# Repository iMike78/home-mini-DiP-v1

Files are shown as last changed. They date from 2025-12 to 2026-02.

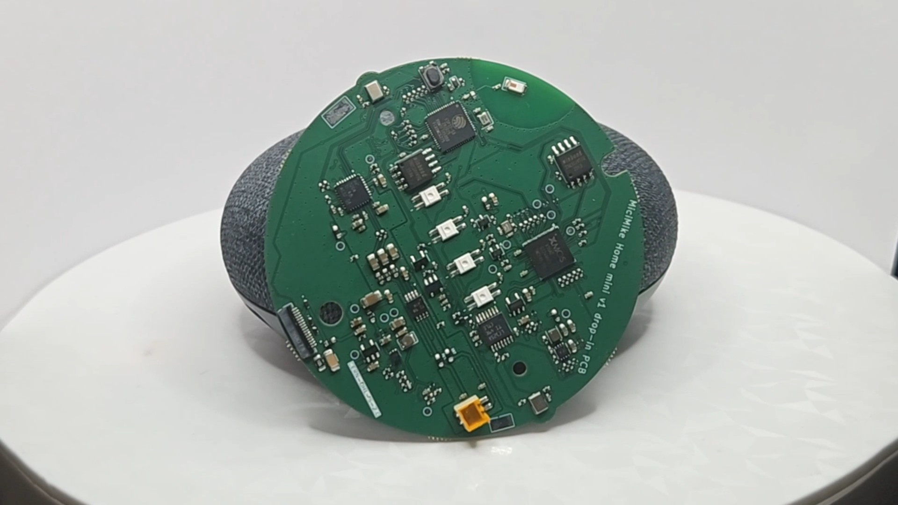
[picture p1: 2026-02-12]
pics/dji_export_photo_20260208104227295.png

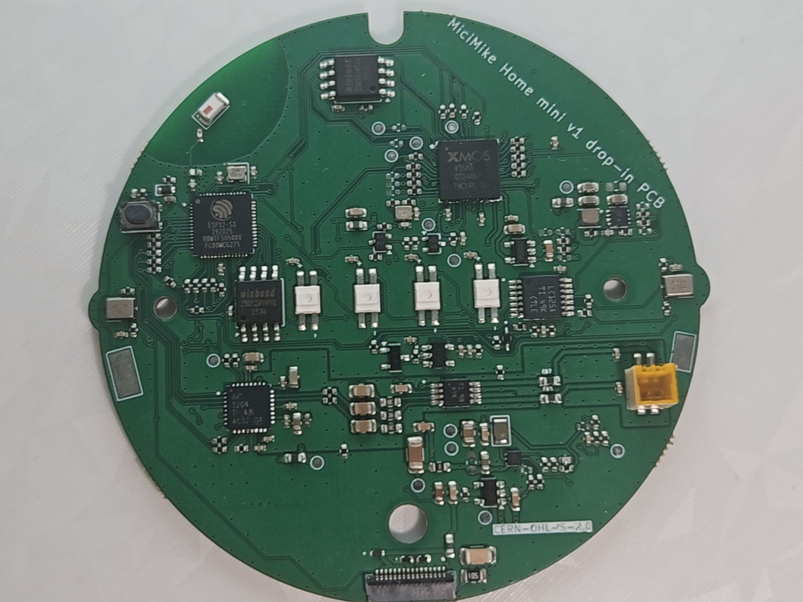
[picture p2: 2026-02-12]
pics/DJI_20260208_104004_14.jpg

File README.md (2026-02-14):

# MiciMike drop-in PCB replacement for Google Home Mini (Gen-1)

[MiciMike Home Mini](https://github.com/iMike78/home-mini-v1-drop-in-pcb) is a drop-in PCB replacement for the ["Google Home Mini" (Google's first-generation smart speaker hardware with a Micro-USB charging port)](https://en.wikipedia.org/wiki/Google_Nest_(smart_speakers)), but based on ESP32 and XMOS microcontrollers for running open-source firmware.

dji_export_photo_20260208104256661

Tip! If you are instead looking for a similar drop-in PCB replacement for the "Google Nest Mini" (Google's second-generation smart speaker with a barrel connector charging port) then check out the sister-project at https://github.com/iMike78/nest-mini-drop-in-pcb

Both of these are fully open-source hardware projects, taking some concep inspiration from the [Onju Voice](https://github.com/justLV/onju-voice) however aiming to follow [Open Home Foundation's open voice assistants standard with Home Assistant Voice Preview Edition as reference](https://www.home-assistant.io/blog/2024/12/19/voice-preview-edition-the-era-of-open-voice/) for PCB designs and specifications.

# Project scope

The goal of this project/repository and its sister-project (which are both similar to the concept in [Onju Voice](https://github.com/justLV/onju-voice) but under a fully open-source hardware license) is to design drop-in replacement PCBs (Printed Circuit Board) with hardware schematics following open voice assistants standard from the Open Home Foundation so that anyone can make or order from a one-stop PCB manufacturer as a custom drop-in replacement PCB for the Google Nest Mini (2nd Gen) to convert it into open-source voice assistant hardware.

These projects is primarly targeting people looking to repurpose their old Google Home Mini (and Google Nest Mini) smart speakers into open-source hardware for [Voice Control of Home Assistant](https://www.home-assistant.io/voice_control/) and/or media player speaker output for [Music Assistant](https://www.music-assistant.io), (the hardware can however probably also be used with other applications as well with other firmware as it is based on the popular Espressif ESP32 platform).

The hardware design will (similar to [Home Assistant Voice Preview Edition](https://www.home-assistant.io/blog/2024/12/19/voice-preview-edition-the-era-of-open-voice/)) integrate an ESP32-S3 microcontroller for WiFi, BLE, and [onboard wake-word detection](https://www.home-assistant.io/voice_control/about_wake_word/) (using the no-code [ESPHome firmware](https://esphome.io/) firmware) + an XMOS xCORE XU316 chip for advanced audio processing (with custom firmware for microphone cleanup offloading for better voice recognition capabilities by using using locally running algorithms for Noise Suppression, Acoustic Echo Cancellation, Interference Cancellation, and Automatic Gain Control).

Again, functionality-wise it is made to be mostly hardware comatible with the [Home Assistant Voice Preview Edition (a.k.a. Home Assistant Voice PE](https://www.home-assistant.io/blog/2024/12/19/voice-preview-edition-the-era-of-open-voice/) reference design (which has been released as open-source hardware design from Open Home Foundation in coolaboration with Nabu Casa). The main difference will be due to very tight constraints defined by the Google Home Mini and Google Nest Mini enclosures and its other comonents, (the design of the replacement PCBs will therefore be limited by the same type of physical capacity inputs as the original hardware from Google).

As such the scope for these projects is not to develop new features/functions for the ESPHome and XMOS firmware, so if you want that then you instead need to turn to the firmware development of the Home Assistant Voice Preview Edition as well as to the upstream ESPHome repositories on GitHub:

- https://github.com/esphome/home-assistant-voice-pe
  - https://github.com/esphome/esphome
    - https://github.com/esphome/voice-kit-xmos-firmware

## Request for collaboration and contributions

If you are a non-developer and would like to show your support me working on these projects please consider [buying me a coffee via Ko-fi](https://ko-fi.com/imike78) ☕ 

If you have experience with board-level electrical design / working with PCB design andlayout in CAD software (epecially with PCB routing and ground pouring in KiCad, or optimizing noise-sensitive digital+analog layouts), then **your help would be highly appreciated**! Please feel free to open a new issue and add comments to existing issues, or start a new discussion in this repository to suggestions/requests/input/feedback.

For reference, you can find some more background information about the original concept/idea see and post to Home Assistant related community discussion in this Home Assistant community forum thread:

- https://community.home-assistant.io/t/any-news-on-alternative-to-onju-voice-pcb-repacement-design-for-google-nest-home-mini-speakers-with-added-xmos-chip-to-match-of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

### Current status

- ✅ Schematic completed
- ✅ Component placement done
- ✅ Routing
- ✅ Ground pour, shielding strategy, and EMI considerations
- ✅ Test run of the first test batch
- ✅ Ready for manufacturing

## Tools used

- 🛠️ KiCad 9
- 🧰 SnapEDA / LCSC for footprint sourcing

## Known hardware specifications

- 4-layer PCB
- ESP32-S3R8 bare chip (ESP32-S3 for WiFi, BLE, and onboard wake-word detection) with 16MB flash
- XMOS XU316-1024-QF60B-C24 (XMOS XU316 xCORE DSP audio processing) with 4MB flash
- Dual I²S buses (to allow I2S interfaces at the same time, i.e. simultaneous audio output and audio input)
- AIC3204 DAC and TPA6211 PA for speaker output
- 2x MEMS microphones (dual T3902 with 68mm inter-mic spacing)
- 4x SK6812 RGB LEDs

## References

### Home Assistant Voice Preview Edition resources including PCB design files
- https://www.home-assistant.io/blog/2024/12/19/voice-preview-edition-the-era-of-open-voice/
  - https://voice-pe.home-assistant.io/resources/
    - https://support.nabucasa.com/hc/en-us/categories/24451727188125-Home-Assistant-Voice-Preview-Edition
      - https://support.nabucasa.com/hc/en-us/sections/24980381645213-Resources

#### ESPHome firmware for Home Assistant Voice PE (which also use the same ESP32-S3 + XMOS XU316 combination):

- https://github.com/esphome/home-assistant-voice-pe
  - https://esphome.github.io/home-assistant-voice-pe/
- https://voice-pe.home-assistant.io/

### XMOS xCORE DSP (XU316-1024-QF60B-C32) MCU IC chip

- https://www.xmos.com/download/XU316-1024-QF60B-xcore.ai-Datasheet(3).pdf
- https://www.xmos.com/software-tools/
  - https://www.xmos.com/develop/xcore-voice
  - https://www.xmos.com/usb-multichannel-audio/
  - https://www.xmos.com/xcore-ai
 
#### XMOS firmware from the ESPHome prokect for the Home Assistant Voice Preview Edition hardware:

- https://github.com/esphome/voice-kit-xmos-firmware
  - https://github.com/esphome/xmos_fwk_rtos
  - https://github.com/esphome/xmos_fwk_io

## License

This project is licensed under the [CERN Open Hardware License Version 2 - Strongly Reciprocal (CERN-OHL-S v2)]
Any modified version of this hardware must also be distributed under the same license.

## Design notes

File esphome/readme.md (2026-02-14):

# MiciMike Factory Firmware Structure

## Overview

The factory firmware structure enables:
1. Minimal factory firmware pre-installed at manufacturing
2. Initial setup via BLE Improv for WiFi configuration
3. Automatic upgrade to full firmware after WiFi connection

## File Structure

```
esphome/
├── micimike-factory.yml          # Factory firmware (manufacturing)
└── micimike-voice.yml            # Full firmware (your current config)
```

## Factory Firmware (micimike-factory.yml)

### Main Components:

1. **Package Import**: Loads the full firmware configuration
   ```yaml
   packages:
     micimike_voice: !include micimike-voice.yml
   ```

2. **BLE Improv Provisioning**: 
   - Uses touch center button for authentication
   - BLE connection for WiFi setup
   
3. **HTTP OTA Update**:
   - Downloads manifest from GitHub releases
   - Automatically updates to full firmware

4. **Beta Firmware Switch**:
   - Enables beta version testing
   - Switches manifest URL between production/beta

## Key Differences from HA VPE:

### 1. Center Button Authorizer
HA VPE: `authorizer: center_button` (physical button)
MiciMike: `authorizer: center_button` (touch button - ESP32-S3 GPIO3)

The touch button works the same as physical:
```yaml
binary_sensor:
  - platform: esp32_touch
    id: center_button
    threshold: 5000
    pin: GPIO3
```

### 2. LED Control
The factory firmware also supports the `control_leds` script:
- During BLE provisioning: `improv_ble_in_progress = true`
- During initialization: `init_in_progress = true`
- After WiFi connection: normal LED operation

## Installation Process

### 1. Flash Factory Firmware (USB)
```bash
esphome run micimike-factory.yml
```

### 2. BLE Improv Provisioning
- Device starts in AP mode
- ESPHome app or Home Assistant discovers it
- Touch center button for authentication
- WiFi configuration

### 3. Automatic Update
- 5 second delay after WiFi connection
- BLE disable
- HTTP OTA downloads manifest
- Automatic update to full firmware
- Reboot with full functionality

## Manifest.json Structure

GitHub releases must contain a manifest.json:

```json
{
  "name": "MiciMike Voice Assistant",
  "version": "v0.9.0",
  "builds": [
    {
      "chipFamily": "ESP32-S3",
      "improv": false,
      "parts": [
        {
          "path": "micimike-voice.bin",
          "offset": 0
        }
      ]
    }
  ]
}
```

## GitHub Releases Structure

```
Releases/
├── v0.9.0/
│   ├── manifest.json           # Production manifest
│   ├── manifest-beta.json      # Beta manifest
│   └── micimike-voice.bin      # Full firmware binary
```

## Benefits

1. **Simple Manufacturing**: Only factory firmware needs to be flashed
2. **OTA Updates**: Users receive full version via WiFi
3. **Beta Channel**: Optional beta firmware testing
4. **No USB Dependency**: After initial flash, everything is OTA
5. **Version Tracking**: GitHub releases-based version management

## Notes

- Touch center button works as authentication just like physical button
- All full configuration functionality is preserved
- Factory firmware contains only bootstrap functions
- LED control works in both versions
- Future Firmware updates are not automatic. Users must manually check for new releases and update via ESPHome Dashboard.

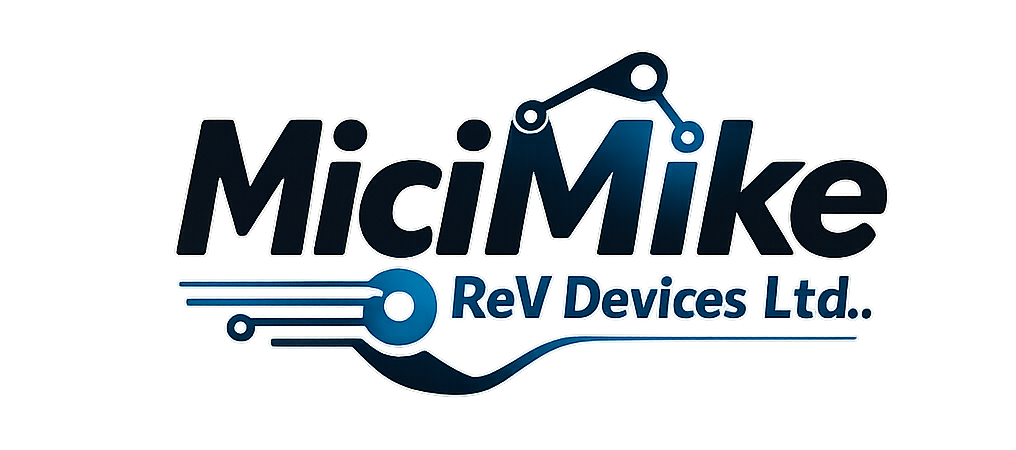
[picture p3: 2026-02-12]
pics/MiciMike.png

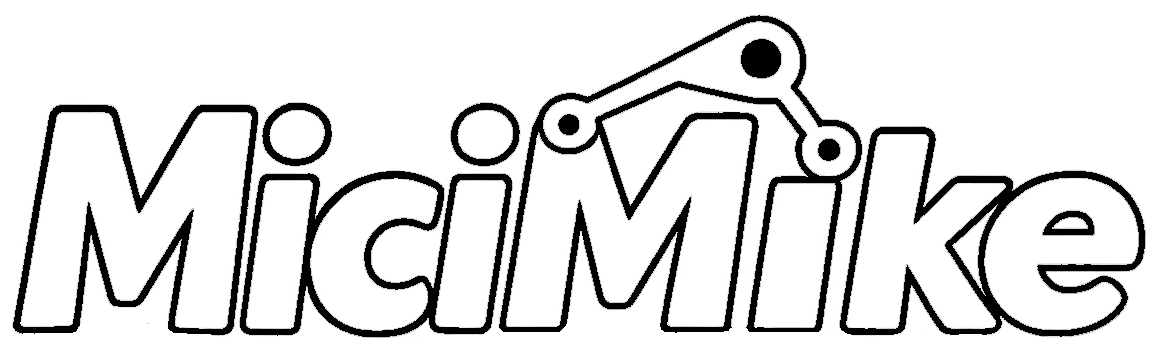
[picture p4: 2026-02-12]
pics/MiciMike_silkscreen.png

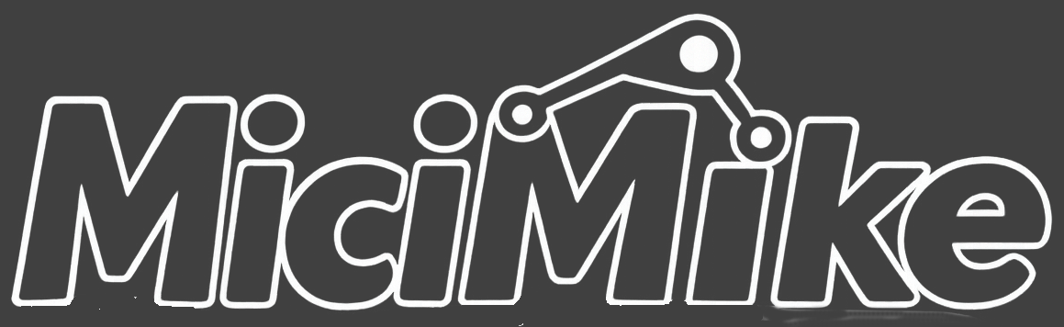
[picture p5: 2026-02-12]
[Originals]/MiciMike_silkscreen.png

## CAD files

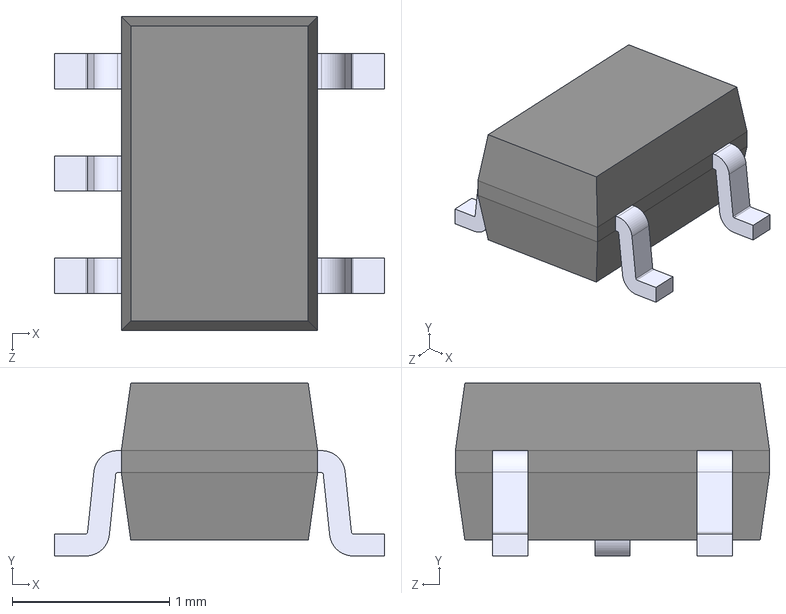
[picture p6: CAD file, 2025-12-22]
parts/MIC5365-1.8YC5-TR.step
2.10 x 1.10 x 2.00 mm

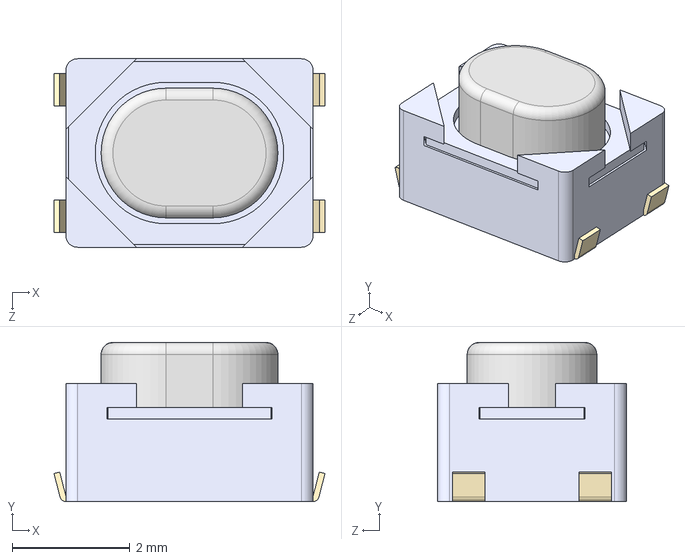
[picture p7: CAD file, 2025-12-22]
parts/PTS810SJS250SMTRLFS--3DModel-STEP-56544.STEP
4.60 x 2.70 x 3.20 mm

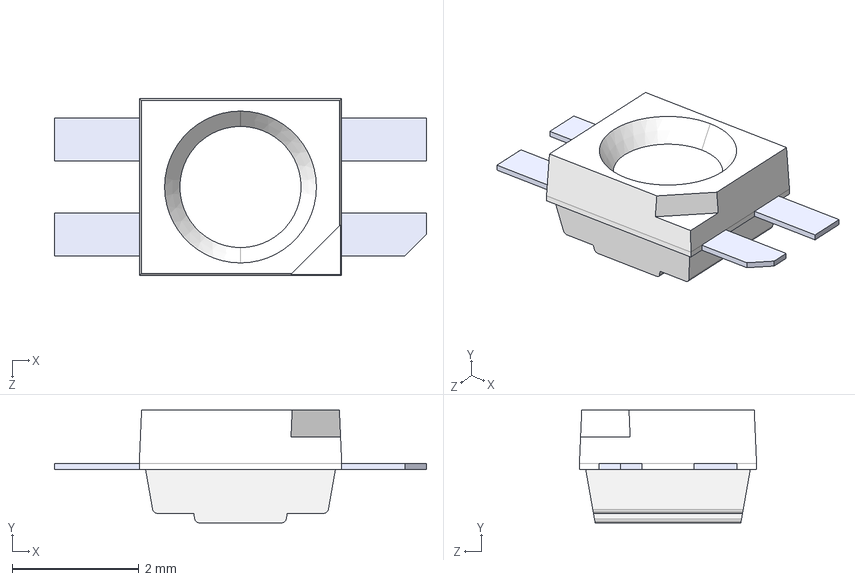
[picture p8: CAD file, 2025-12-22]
parts/SK6812-E.step
5.88 x 1.78 x 2.80 mm

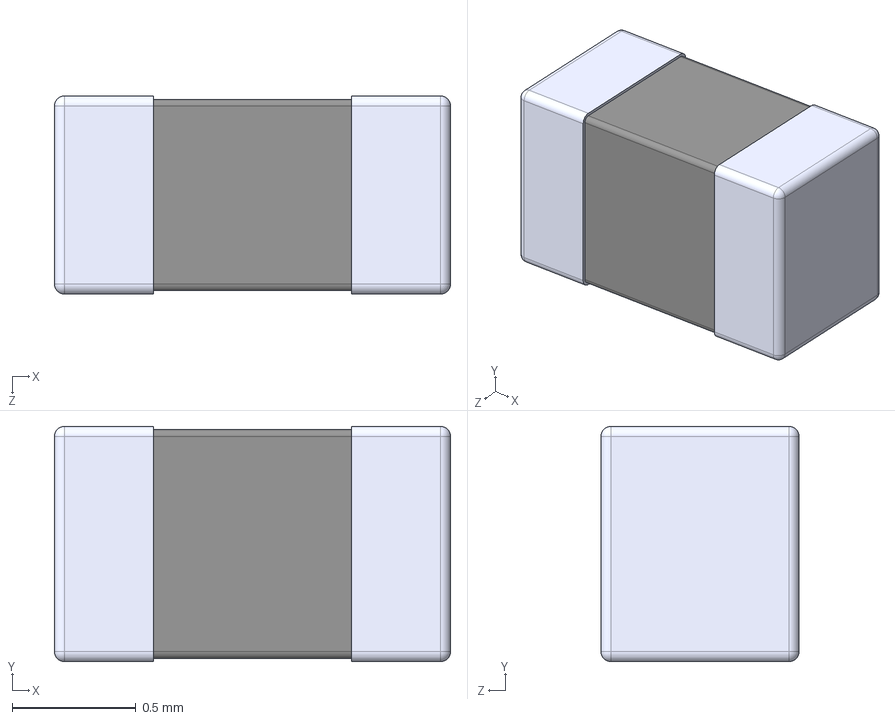
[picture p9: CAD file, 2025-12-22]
parts/BLM18PG121SN1D.step
1.60 x 0.95 x 0.8 mm

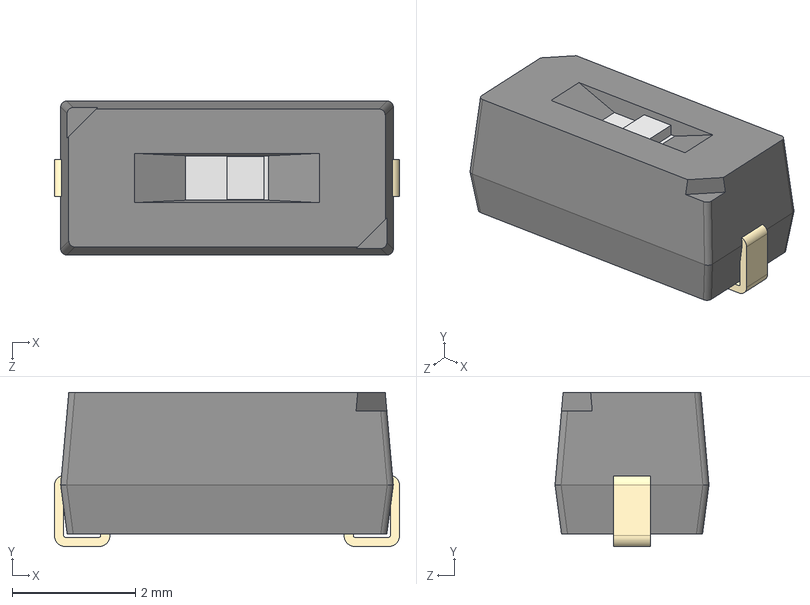
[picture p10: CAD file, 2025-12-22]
parts/CHS-01TA.step
5.60 x 2.50 x 2.50 mm
CHS-01 body
pin^CHS-01xx
switch^CHS-01xx

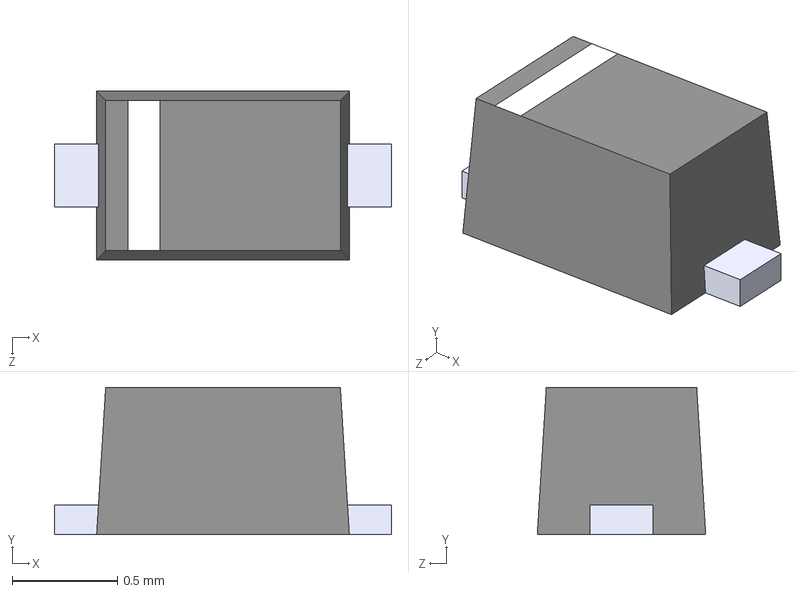
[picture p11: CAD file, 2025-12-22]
parts/RB521S30T1G.step
1.60 x 0.7 x 0.8 mm

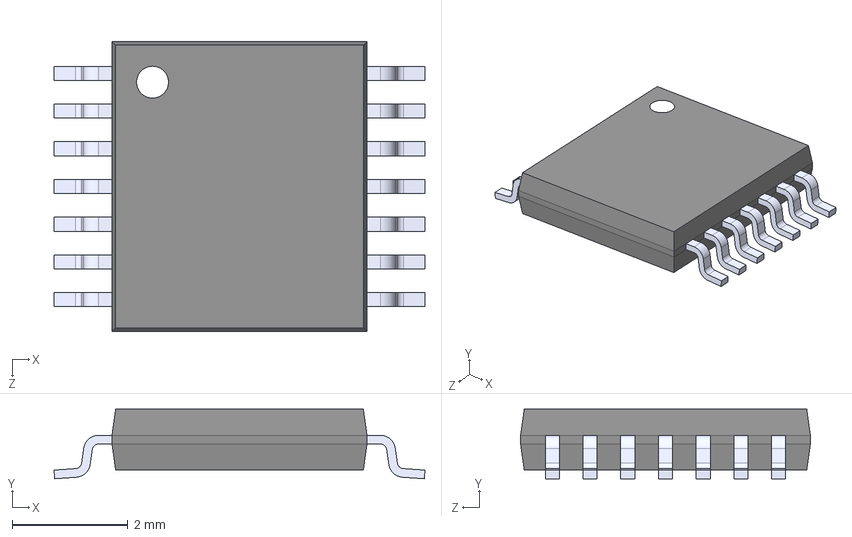
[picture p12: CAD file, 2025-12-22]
parts/SN74LVC125APWR.step
6.40 x 1.20 x 5.00 mm

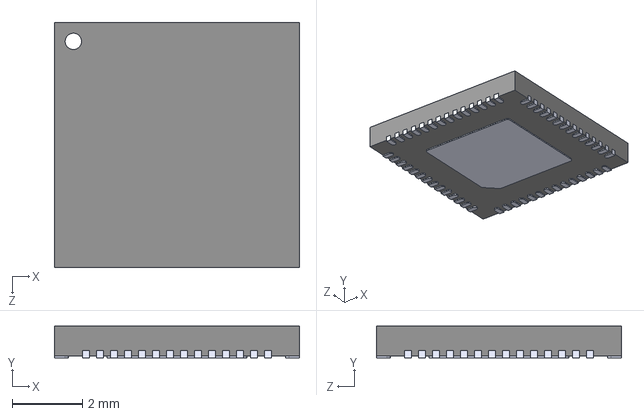
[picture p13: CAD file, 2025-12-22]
parts/ESP32-S3R8.step
7.00 x 0.9 x 7.00 mm

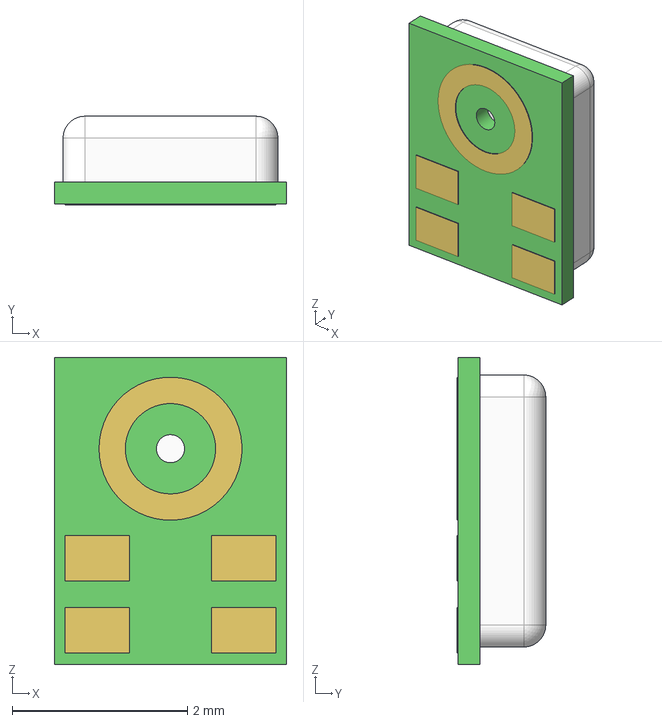
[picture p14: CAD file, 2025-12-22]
parts/DMM-3526-B-R.step
2.65 x 1.01 x 3.50 mm

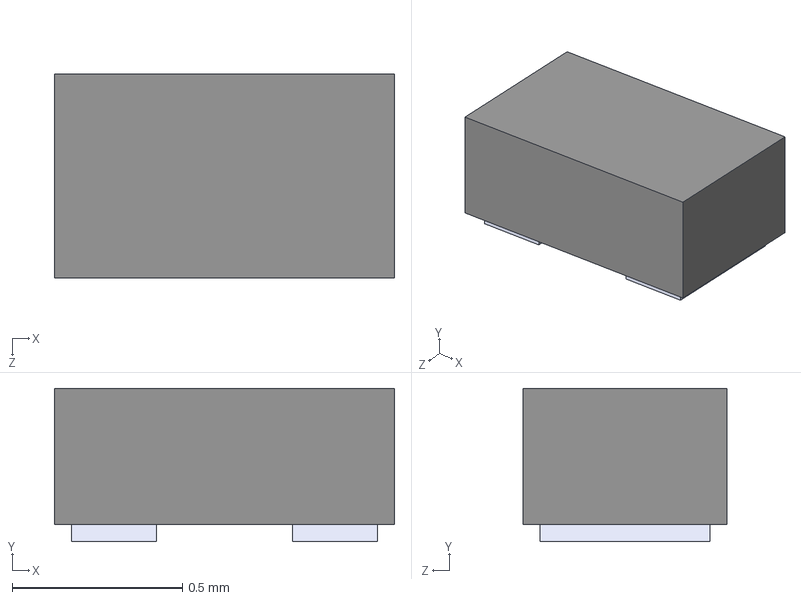
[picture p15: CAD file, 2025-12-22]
parts/TPD1E10B06DPYR.step
1.00 x 0.45 x 0.6 mm

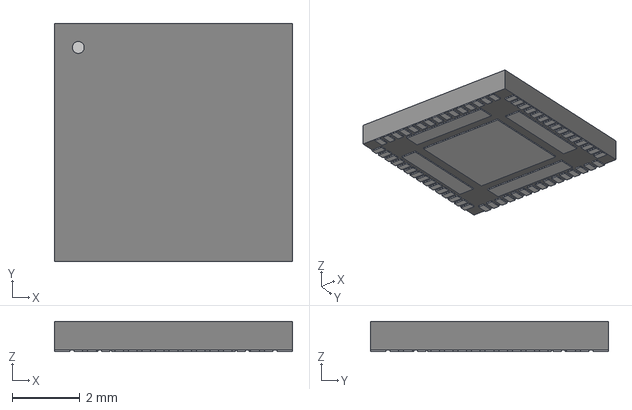
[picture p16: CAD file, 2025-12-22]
parts/QFN_F60B-C24_XMO.step
7.01 x 7.01 x 0.892 mm

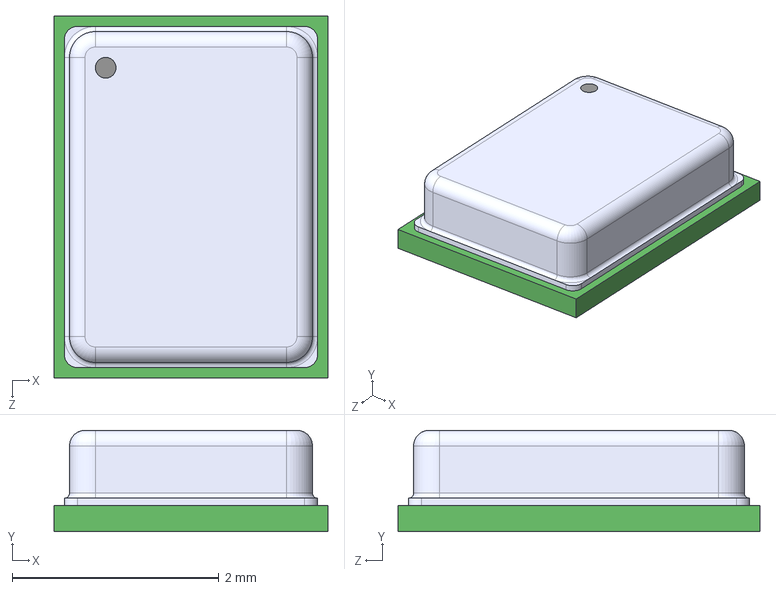
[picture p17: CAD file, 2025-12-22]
parts/T3902.step
2.65 x 0.98 x 3.50 mm

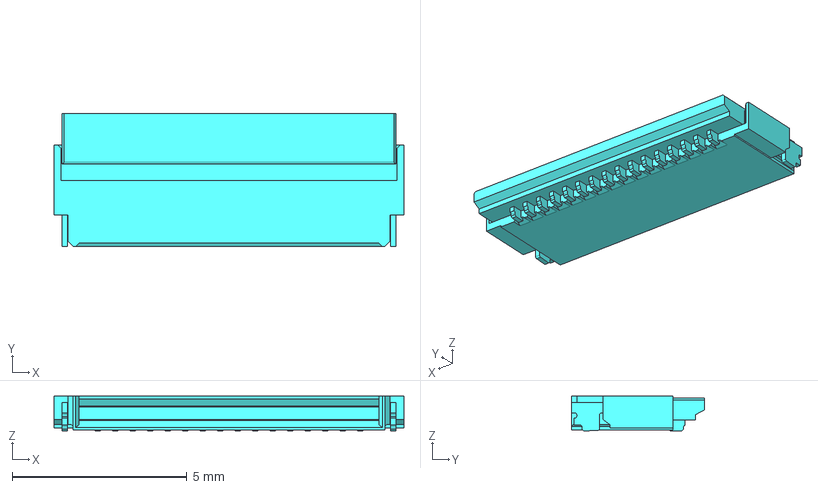
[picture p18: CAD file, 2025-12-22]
parts/FH34SRJ-16S-0.5SH-99---3DModel-STEP-1.STEP
10.0 x 3.80 x 1.00 mm

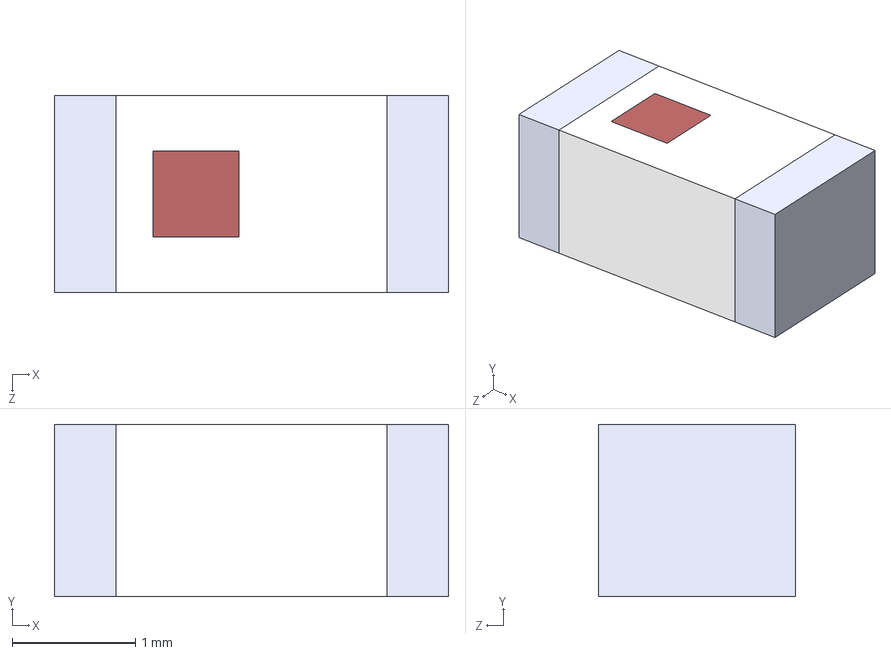
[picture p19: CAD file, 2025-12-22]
parts/2450AT18A100E.step
3.20 x 1.40 x 1.60 mm

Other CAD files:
parts/MAX98357AETE_T.step
parts/1775443-2.stp
parts/TLV73333PDBVR.step
parts/TPS563201DDCT.step

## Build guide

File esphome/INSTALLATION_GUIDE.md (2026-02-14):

# MiciMike Factory Firmware - Complete Guide

## 1. Project Structure Setup

### File placement in GitHub repo:

```
home-mini-DiP-v1/
├── .github/
│   └── workflows/
│       └── build.yml                    # Automatic build
├── esphome/
│   ├── micimike-factory.yml            # Factory firmware
│   └── micimike-voice.yml              # Full firmware (current config)
├── manifests/
│   ├── manifest.json                    # Production manifest
│   └── manifest-beta.json               # Beta manifest
└── README.md
```

## 2. Setup Steps

### 2.1. File Creation

1. **micimike-factory.yml** - Already created ✓
2. **micimike-voice.yml** - Your current full configuration
3. **manifest.json** - GitHub releases manifest
4. **manifest-beta.json** - Beta version manifest
5. **GitHub Actions workflow** - Automatic build

### 2.2. GitHub Repository Setup

```bash
# Add files
git add esphome/micimike-factory.yml
git add esphome/micimike-voice.yml
git add manifests/manifest.json
git add manifests/manifest-beta.json
git add .github/workflows/build.yml

# Commit
git commit -m "Add factory firmware structure"

# Push
git push origin main
```

### 2.3. Create First Release

```bash
# Create tag
git tag v0.9.0

# Push tag
git push origin v0.9.0
```

GitHub Actions will automatically:
- Build factory and full firmware
- Create the release
- Upload binary files and manifests

## 3. Using Factory Firmware

### 3.1. Initial Installation (USB)

```bash
# Flash factory firmware
esphome run esphome/micimike-factory.yml
```

### 3.2. BLE Improv Provisioning

1. **Power on device**
   - LED ring animation indicates BLE Improv mode

2. **ESPHome app or Home Assistant**
   - Bluetooth search
   - "micimike" device appears

3. **Touch center button**
   - Press button for authentication
   - LED feedback

4. **WiFi configuration**
   - Select SSID
   - Enter password
   - Connect

### 3.3. Automatic Update

After connection, automatically:

1. **5 sec delay** - Allow improv results transmission
2. **BLE disable** - Bluetooth turns off
3. **LED refresh** - control_leds script runs
4. **HTTP OTA** - Download manifest from GitHub
5. **Firmware update** - Install full firmware
6. **Reboot** - Full functionality available

## 4. OTA Updates

### 4.1. Production Updates

When creating new release:

```bash
git tag v0.9.1
git push origin v0.9.1
```

Device automatically detects and installs.

### 4.2. Beta Updates

In Home Assistant:

1. **Enable Beta Firmware switch**
2. **Check Update entity**
3. **Install update**

### 4.3. Return to Production

1. **Disable Beta Firmware switch**
2. **Check Update entity**
3. **Install production version**

## 5. LED Feedback

### BLE Improv Mode
- `improv_ble_in_progress = true`
- Special LED animation

### Initialization
- `init_in_progress = true`
- Waiting animation
- Auto-disable after 10 minutes

### WiFi Connection
- Connected: `control_leds` runs
- Disconnected: BLE enable

### Center Button Touch
- LED brightness increase
- Visual feedback

## 6. Manifest URL Structure

### Production
```
https://github.com/iMike78/home-mini-DiP-v1/releases/latest/download/manifest.json
```

### Beta
```
https://github.com/iMike78/home-mini-DiP-v1/releases/latest/download/manifest-beta.json
```

## 7. Troubleshooting

### BLE Improv Not Working
1. Check touch threshold (currently 5000)
2. ESP32 touch calibration may be needed
3. Check setup mode logs

### OTA Update Failed
1. GitHub releases accessibility
2. Manifest.json correctness
3. Binary files accessibility
4. WiFi connection stability

### LED Not Responding
1. `control_leds` script error
2. Global variables initialization
3. Binary sensor states check

## 8. Touch Center Button Calibration

If authentication doesn't work:

```yaml
esp32_touch:
  setup_mode: True  # Enable temporarily
  # ... other settings
```

Based on log values, adjust:

```yaml
binary_sensor:
  - platform: esp32_touch
    id: center_button
    pin: GPIO3
    threshold: XXXX  # Calibrate this value
```

## 9. Factory Reset

Hold touch center button for 22 seconds:
- 10 sec: Warning (sound + LED)
- 22 sec: Confirmation (sound + red LED)
- Release: Execute factory reset

## 10. Special Features

### Easter Egg
H-A morse code: 
- Tick animation
- Tada sound
- Rainbow LED effect

### Volume Tick
- Custom sound during volume change
- LED volume display

### Timer
- Timer ring mode
- Stop wake word active
- Auto-stop after 15 minutes

## 11. Next Steps

1. ✓ Factory firmware file created
2. ✓ Manifest.json files
3. ✓ GitHub Actions workflow
4. □ Push files to GitHub
5. □ Create first release
6. □ Test factory firmware
7. □ Touch button calibration
8. □ Test OTA updates

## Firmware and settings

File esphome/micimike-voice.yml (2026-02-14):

substitutions:
  # Phases of the Voice Assistant
  # The voice assistant is ready to be triggered by a wake word
  voice_assist_idle_phase_id: '1'
  # The voice assistant is waiting for a voice command (after being triggered by the wake word)
  voice_assist_waiting_for_command_phase_id: '2'
  # The voice assistant is listening for a voice command
  voice_assist_listening_for_command_phase_id: '3'
  # The voice assistant is currently processing the command
  voice_assist_thinking_phase_id: '4'
  # The voice assistant is replying to the command
  voice_assist_replying_phase_id: '5'
  # The voice assistant is not ready
  voice_assist_not_ready_phase_id: '10'
  # The voice assistant encountered an error
  voice_assist_error_phase_id: '11'
  # Change this to true in case you ahve a hidden SSID at home.
  hidden_ssid: "false"
  # Substitutions for audio files
  mute_switch_on_sound_file: https://github.com/esphome/home-assistant-voice-pe/raw/dev/sounds/mute_switch_on.flac
  mute_switch_off_sound_file: https://github.com/esphome/home-assistant-voice-pe/raw/dev/sounds/mute_switch_off.flac
  timer_finished_sound_file: https://github.com/esphome/home-assistant-voice-pe/raw/dev/sounds/timer_finished.flac
  wake_word_triggered_sound_file: https://github.com/esphome/home-assistant-voice-pe/raw/dev/sounds/wake_word_triggered.flac
  volume_tick_sound_file: https://raw.githubusercontent.com/iMike78/home-mini-DiP-v1/main/sounds/volume.flac
  center_button_press_sound_file: https://github.com/esphome/home-assistant-voice-pe/raw/dev/sounds/center_button_press.flac
  center_button_double_press_sound_file: https://github.com/esphome/home-assistant-voice-pe/raw/dev/sounds/center_button_double_press.flac
  center_button_triple_press_sound_file: https://github.com/esphome/home-assistant-voice-pe/raw/dev/sounds/center_button_triple_press.flac
  center_button_long_press_sound_file: https://github.com/esphome/home-assistant-voice-pe/raw/dev/sounds/center_button_long_press.flac
  factory_reset_initiated_sound_file: https://github.com/esphome/home-assistant-voice-pe/raw/dev/sounds/factory_reset_initiated.mp3
  factory_reset_cancelled_sound_file: https://github.com/esphome/home-assistant-voice-pe/raw/dev/sounds/factory_reset_cancelled.mp3
  factory_reset_confirmed_sound_file: https://github.com/esphome/home-assistant-voice-pe/raw/dev/sounds/factory_reset_confirmed.mp3
  easter_egg_tick_sound_file: https://github.com/esphome/home-assistant-voice-pe/raw/dev/sounds/easter_egg_tick.mp3
  easter_egg_tada_sound_file: https://github.com/esphome/home-assistant-voice-pe/raw/dev/sounds/easter_egg_tada.mp3
  error_cloud_expired_sound_file: https://github.com/esphome/home-assistant-voice-pe/raw/dev/sounds/error_cloud_expired.mp3
  name: micimike
  friendly_name: MiciMike voice assistant

esphome:
  name: "${name}"
  friendly_name: "${friendly_name}"
  project: 
    name: imike78.micimike
    version: v0.9.0
  name_add_mac_suffix: true
  min_version: 2025.12.0
  on_boot:
    - priority: 375
      then:
        # Run the script to refresh the LED status
        - script.execute: control_leds
        - delay: 1s
        - switch.turn_on: internal_speaker_amp
        # If after 10 minutes, the device is still initializing (It did not yet connect to Home Assistant), turn off the init_in_progress variable and run the script to refresh the LED status
        - delay: 10min
        - if:
            condition:
              lambda: return id(init_in_progress);
            then:
              - lambda: id(init_in_progress) = false;
              - script.execute: control_leds

dashboard_import:
  package_import_url: github://iMike78/home-mini-DiP-v1/esphome/micimike-factory.yml@main
  import_full_config: true

esp32:
  board: esp32-s3-devkitc-1
  cpu_frequency: 240MHz
  variant: esp32s3
  flash_size: 16MB
  framework:
    type: esp-idf
    version: recommended
    sdkconfig_options:
      CONFIG_ESP32S3_DATA_CACHE_64KB: "y"
      CONFIG_ESP32S3_DATA_CACHE_LINE_64B: "y"
      CONFIG_ESP32S3_INSTRUCTION_CACHE_32KB: "y"

      # Moves instructions and read only data from flash into PSRAM on boot.
      # Both enabled allows instructions to execute while a flash operation is in progress without needing to be placed in IRAM.
      # Considerably speeds up mWW at the cost of using more PSRAM.
      CONFIG_SPIRAM_RODATA: "y"
      CONFIG_SPIRAM_FETCH_INSTRUCTIONS: "y"

      CONFIG_BT_ALLOCATION_FROM_SPIRAM_FIRST: "y"
      CONFIG_BT_BLE_DYNAMIC_ENV_MEMORY: "y"

      CONFIG_MBEDTLS_EXTERNAL_MEM_ALLOC: "y"
      CONFIG_MBEDTLS_SSL_PROTO_TLS1_3: "y"  # TLS1.3 support isn't enabled by default in IDF 5.1.5

wifi:
  id: wifi_id
  output_power: 8.5dB
  power_save_mode: none
  reboot_timeout: 10min
  ap:
    ssid: "${friendly_name} Setup"
    password: "12345678"
  on_connect:
    - script.execute: control_leds
  on_disconnect:
    - script.execute: control_leds

captive_portal:
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

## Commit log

2025-12-22 initial upload
    [1775443-2.stp, 2450AT18A100E.step, BLM18AG601SN1D.STEP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]
2025-12-22 Update README to remove PCB ordering details
    Removed outdated information about PCB ordering and installation.
2026-01-06 1st test batch
    [audio.kicad_sch, esp32.kicad_sch, leds.kicad_sch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]
2026-01-10 folder tree cleanup
    [esp32.kicad_sch]
2026-02-12 Production update
    [audio.kicad_sch, esp32.kicad_sch, home-mini-DiP-v1.csv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]
